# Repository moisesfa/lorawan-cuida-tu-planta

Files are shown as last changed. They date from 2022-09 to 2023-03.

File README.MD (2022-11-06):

# LoRaWAN Cuida Tu Planta

Pretendo desarrollar un nodo LoRaWAN para monitorizar las condiciones ambientales en las que crece una planta.

El cerebro será la placa de desarrollo [CubeCell](https://heltec.org/project/htcc-ab01/) del fabricante [Heltec Automation](https://heltec.org/). La placa a día de hoy (Septiembre de 20022), no se recomienda para diseños nuevos y le han puesto la etiqueta Phaseout. El fabricante recomienda una CubeCell-Dev-Board (V2) de la que todavía no hay documentación. Esto carece de importancia en este proyecto que pretende ser meramente educativo. También, pueden ser interesantes las modificaciones a la nueva versión en un futuro.
En Octubre de 2022 ya hay documentación de la versión 2 de la [CubeCell-Dev-Board](https://heltec.org/project/htcc-ab01-v2/). A falta de pruebas, parece que va a ser compatible con la placa diseñada.  

Se ha diseñado un circuito impreso para alimentar el circuito con una batería 18650 y poder conectar fácilmente los sensores i2c a usar. Vea la documentación [aquí](/hardware/README.md)

Temperatura, Humedad, Presión Atmosférica se obtendran con el sensor [BME280](https://www.luisllamas.es/sensor-ambiental-arduino-bme280/)

Para el nivel de luz, un sensor digital [BH1750](https://www.luisllamas.es/medir-cantidad-de-luxes-con-arduino-y-el-luxometro-bh1750/)

El sensor de humedad del suelo será un [higrómetro capacitivo](https://www.luisllamas.es/sensor-de-humedad-del-suelo-capacitivo-y-arduino/) para el que necesitaremos un conversor analógico digital (ADC) como el [ADS1115](https://www.luisllamas.es/entrada-analogica-adc-de-16-bits-con-arduino-y-ads1115/) ya que la CubeCell no dispone de entradas analógicas libres. Esto también nos dará la posibilidad de conectar hasta 4 sensores de humedad de suelo. 

<div style="text-align: center;">

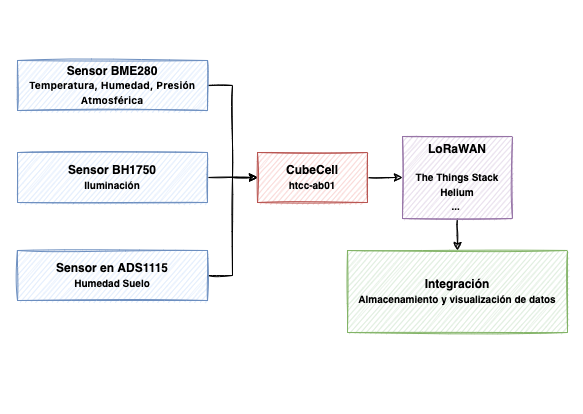
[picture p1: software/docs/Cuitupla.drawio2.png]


</div>

## Fases del proyecto 

- Lectura de los sensores con el puerto serie.
    - [BME280](/software/02_inicio_bme280/README.md)
    - [BH1750](/software/03_inicio_bh1750/README.md)
    - [Conversor analógico-digital para humedad del suelo](/software/04_inicio_ads1115/README.md)
    - [Lectura de todos los sensores](/software/05_sensores_todos/README.md)

- Envio de datos LoRaWAN
    - [Inicio con LoRaWAN](/software/06_inicio_lorawan/README.md)
    - [Lectura de los sensores a LoRaWAN](/software/07_sensores_lorawan/README.md)

## Resultado final

Para proteger el sensor de humedad del suelo he seguido estas [instrucciones](https://www.instructables.com/Waterproofing-a-Capacitance-Soil-Moisture-Sensor/)

El sensor de luminosidad se ha usado en este [formato de bola](https://a.aliexpress.com/_ExYB4vB) para una mejor colocación.

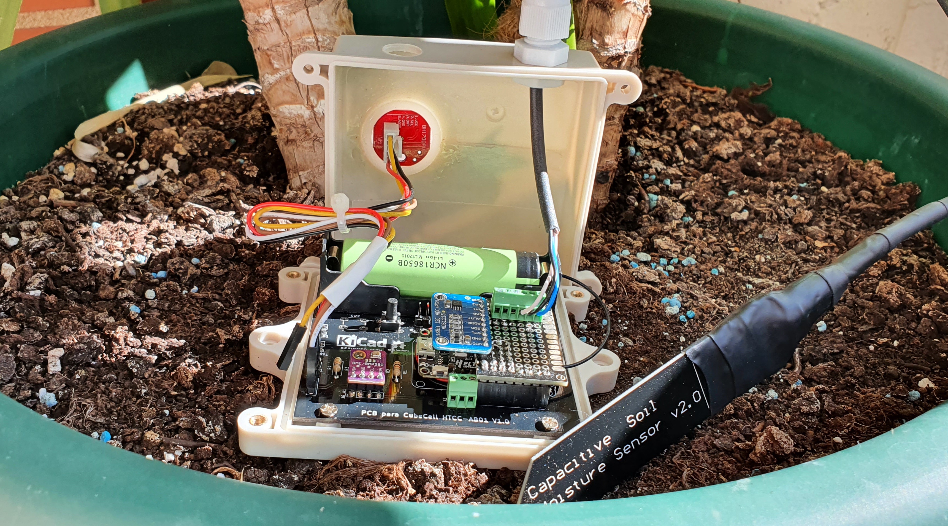
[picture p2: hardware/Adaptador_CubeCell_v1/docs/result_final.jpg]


## Análisis de consumo

He analizado el consumo con el [Power-Profiler-Kit-2](https://www.nordicsemi.com/Products/Development-hardware/Power-Profiler-Kit-2) y dejo aquí los resultados.

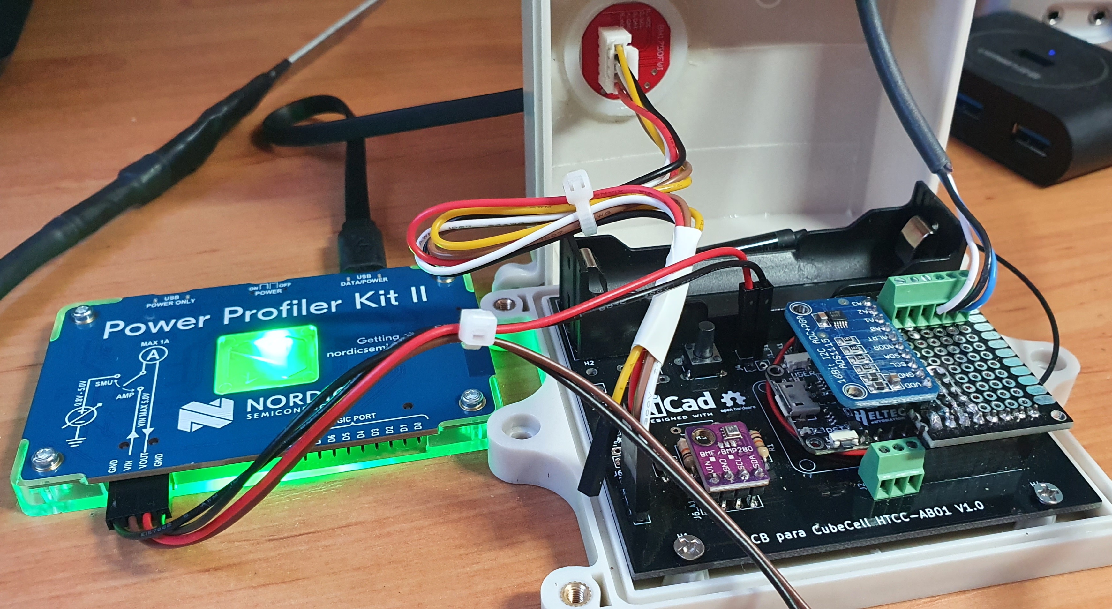
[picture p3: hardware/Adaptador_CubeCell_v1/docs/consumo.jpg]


<div style="text-align: center;">

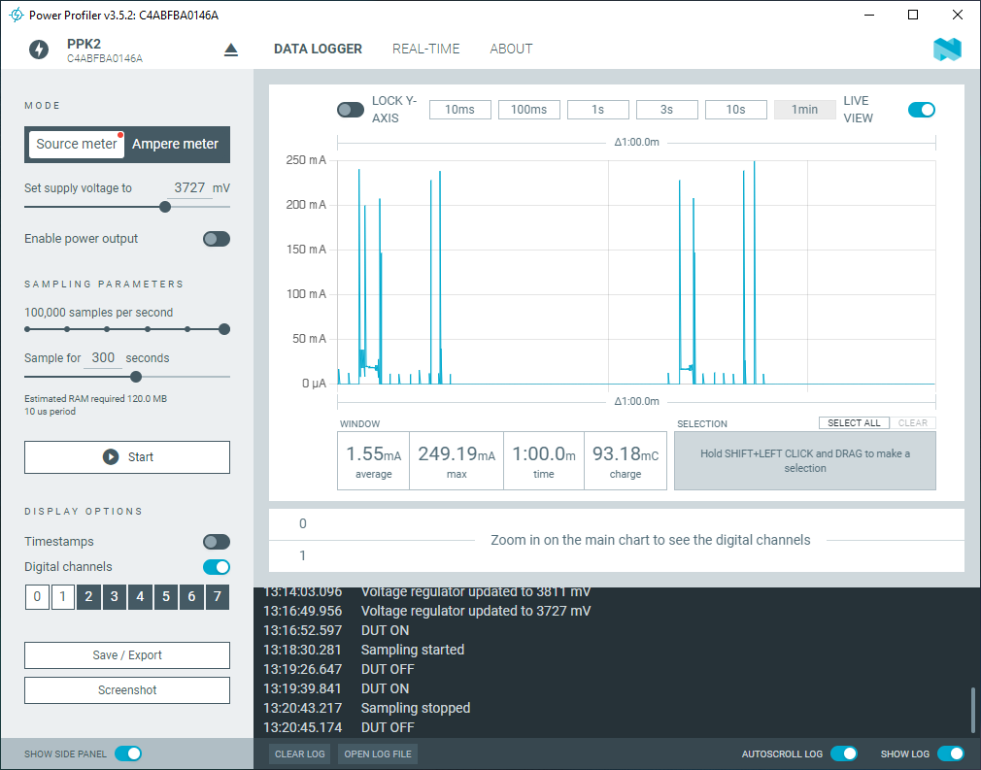
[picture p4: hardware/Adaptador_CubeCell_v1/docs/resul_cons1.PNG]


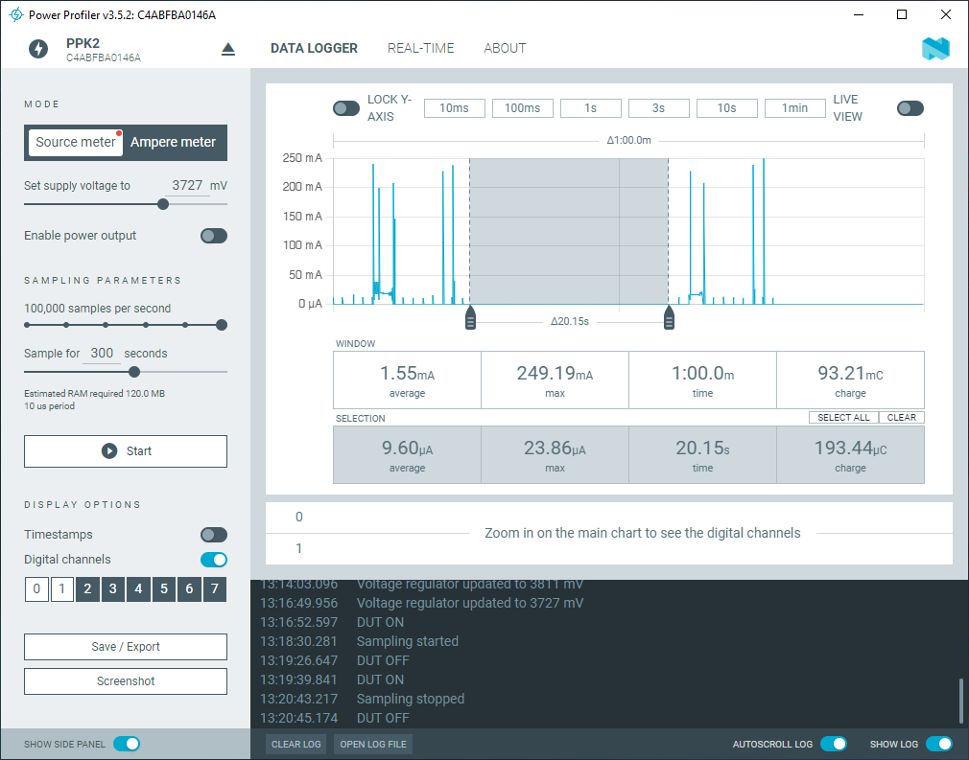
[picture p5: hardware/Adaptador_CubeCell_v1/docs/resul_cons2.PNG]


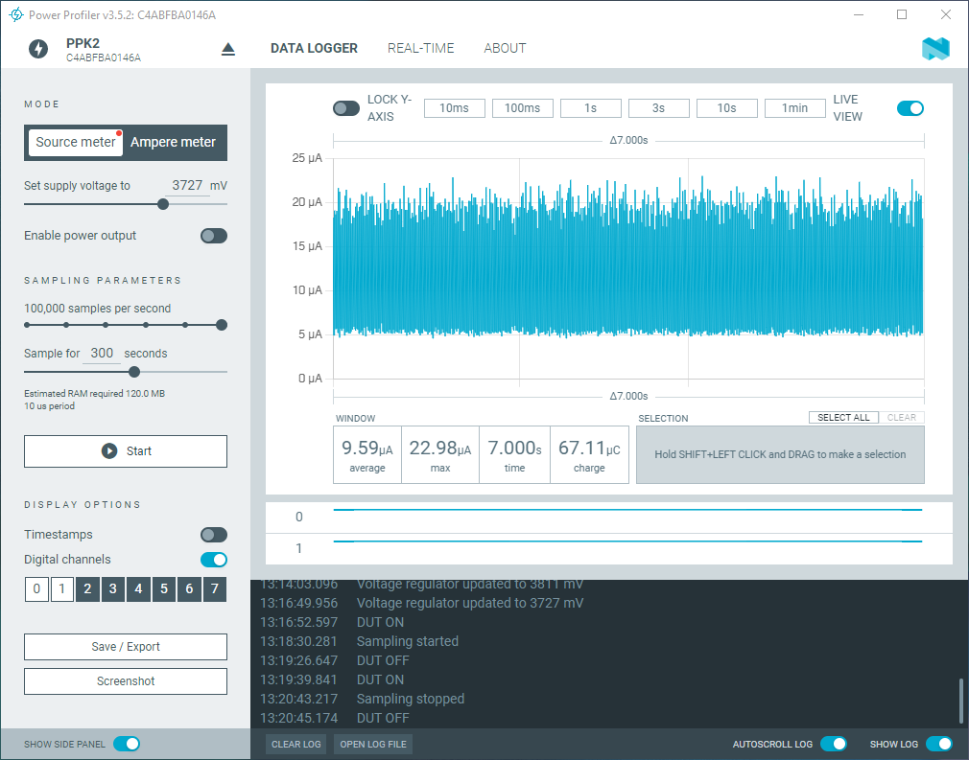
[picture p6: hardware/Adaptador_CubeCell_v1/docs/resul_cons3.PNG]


</div>

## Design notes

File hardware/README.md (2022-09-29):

# Documentación sobre circuito impreso adaptador

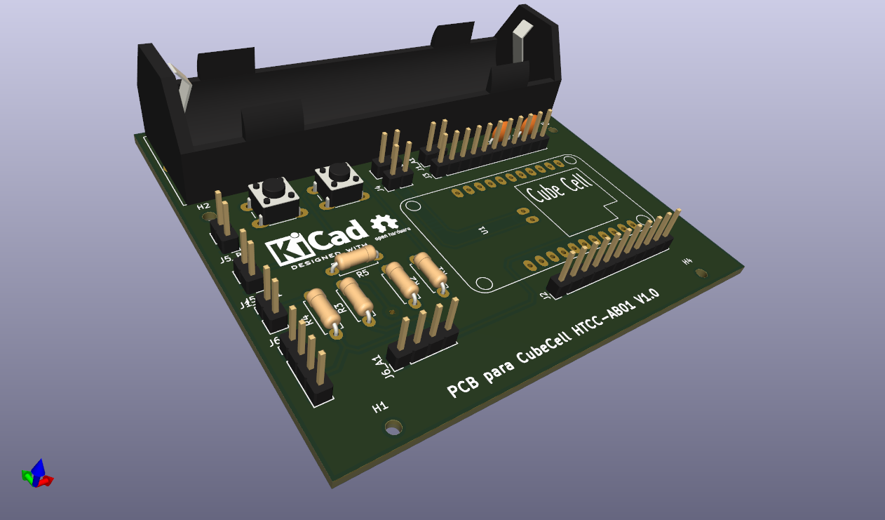
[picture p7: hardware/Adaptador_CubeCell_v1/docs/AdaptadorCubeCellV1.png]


[Esquema](./Adaptador_CubeCell_v1/docs/Adaptador_CubeCell_v1_sch.pdf) y [PCB](./Adaptador_CubeCell_v1/docs/Adaptador_CubeCell_v1_pcb.pdf) diseñados con [Kicad](https://www.kicad.org/)

Se ha diseñado para que se pueda alojar en esta [caja](https://a.aliexpress.com/_dWu4tJt)  

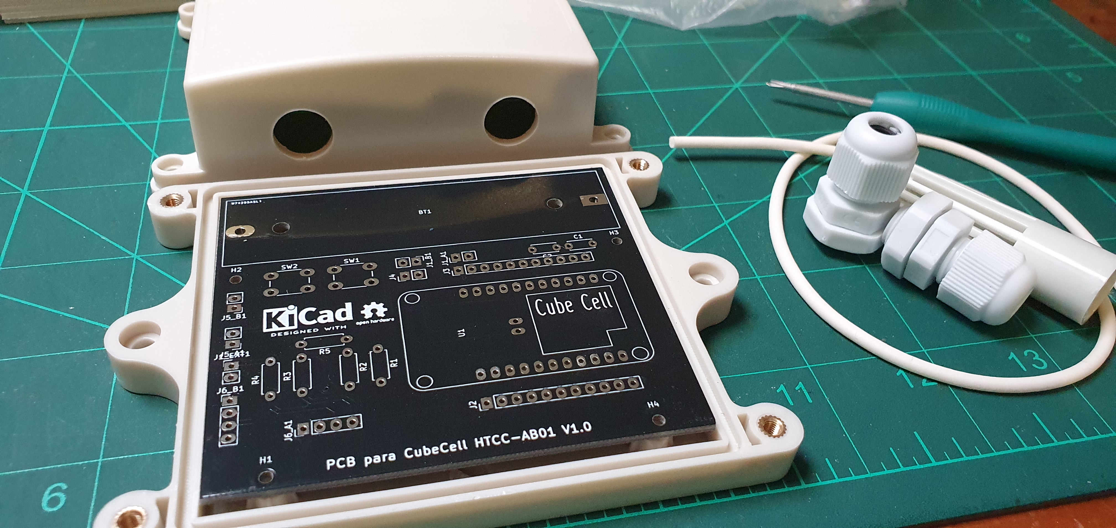
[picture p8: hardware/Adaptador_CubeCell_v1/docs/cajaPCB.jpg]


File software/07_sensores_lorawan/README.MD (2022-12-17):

# sensores_lorawan
 
Este programa lee los todos los sensores y envía la información a LoRaWAN con solo cambiar esta parte del código por las appEui[], devEui[] y appKey[] de su nodo final:

````
/* OTAA para*/
uint8_t appEui[] = { 0x00, 0x00, 0x00, 0x00, 0x00, 0x00, 0x00, 0x00 }; // your appEui
uint8_t devEui[] = { 0x00, 0x00, 0x00, 0x00, 0x00, 0x00, 0x00, 0x00 }; // your devEui
uint8_t appKey[] = { 0x00, 0x00, 0x00, 0x00, 0x00, 0x00, 0x00, 0x00, 0x00, 0x00, 0x00, 0x00, 0x00, 0x00, 0x00, 0x00 }; // your appKey
````

Practicamente todo se basa en la [documentación de Heltec Automation](https://github.com/HelTecAutomation/CubeCell-Arduino/tree/master/libraries/LoRa/examples/LoRaWAN).

El ciclo de trabajo de la aplicación es el siguiente:

1. Se une con la aplicación LoRaWAN.
2. Lee y envía los datos a LoRaWAN.
3. Se duerme durante un tiempo appTxDutyCycle = 30 * 1000; (30 segundos para pruebas).
4. Se despierta, lee los sensores y vuelve a enviar los datos.
5. Los pasos 3 y 4 se repiten hasta que la batería se agota o se resetea el dispositivo.

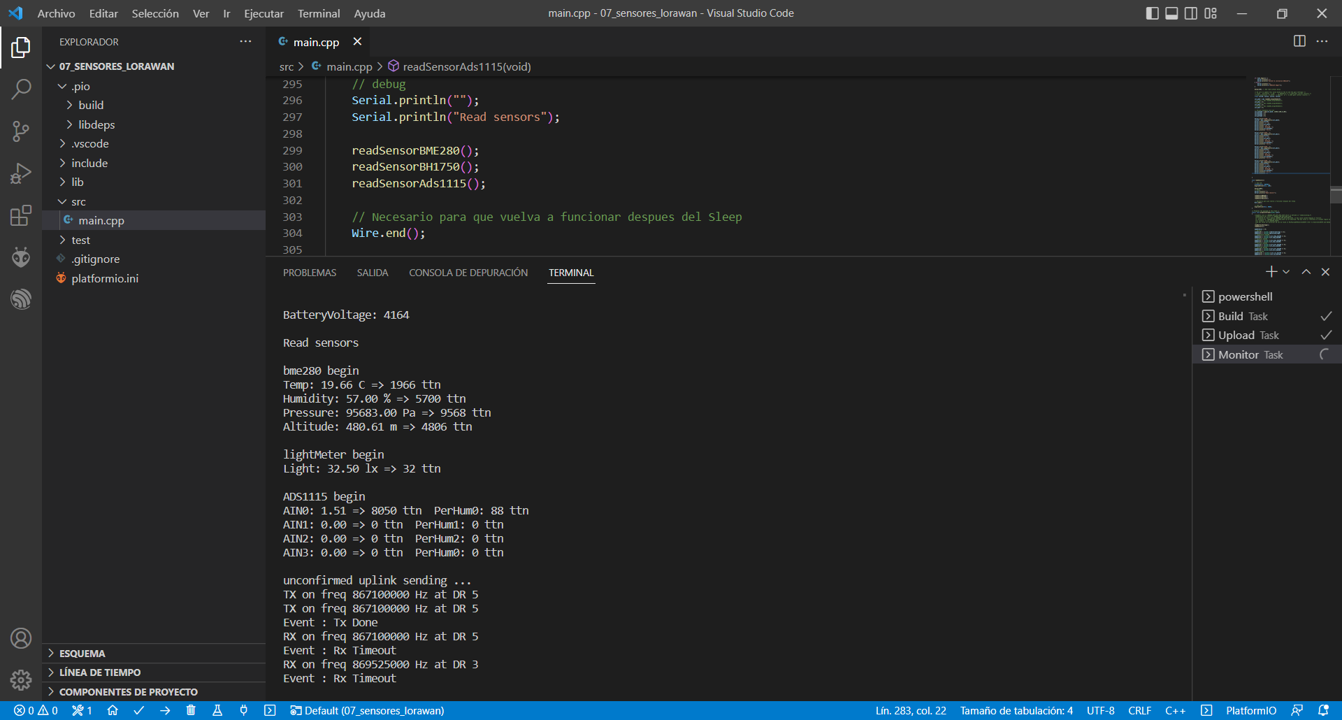
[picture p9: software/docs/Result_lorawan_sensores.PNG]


Ejemplo en The Things Stack: 

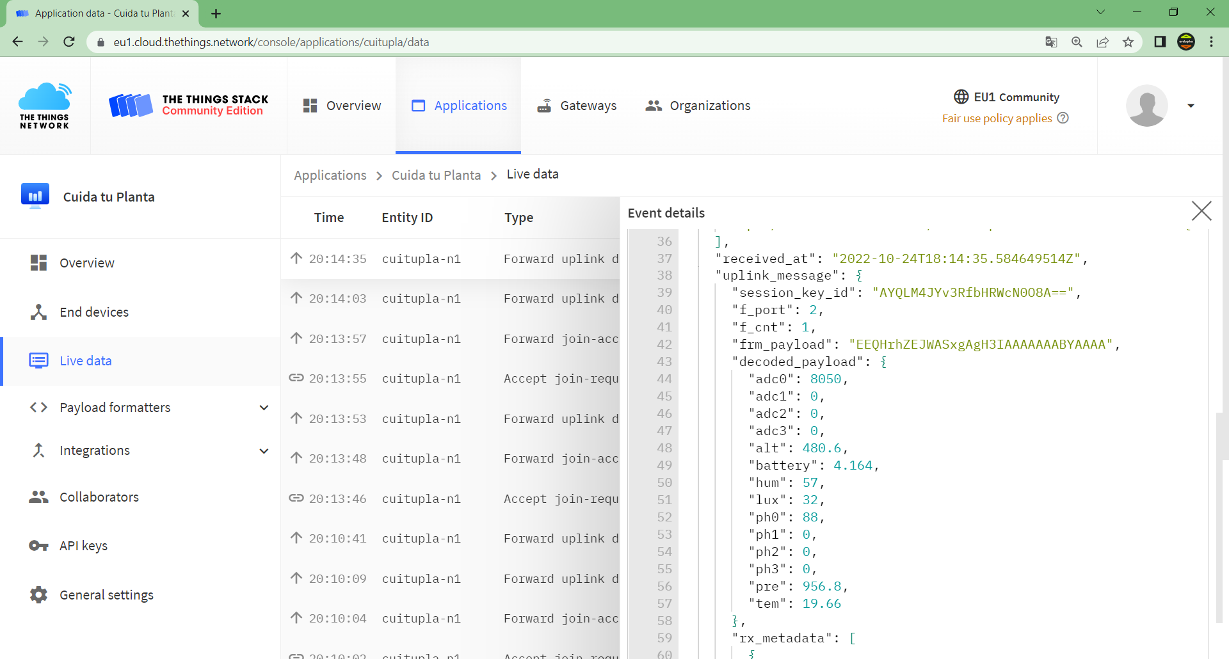
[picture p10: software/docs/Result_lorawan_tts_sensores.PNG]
Ejemplo en The Things Stack


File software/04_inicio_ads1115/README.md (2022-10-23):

# inicio_ads1115
 
Este programa lee los valores de un sensor analógico que será un sensor de humedad del suelo, usando el programa alojado en la [documentación de cubecell](https://github.com/HelTecAutomation/CubeCell-Arduino/blob/master/libraries/Sensor_ThirdParty/examples/ADS1X15/singleended/singleended.ino) y adaptado para [PlatformIO](https://platformio.org/). Funciona con la librería de [Adafruit_ADS1x15](https://github.com/adafruit/Adafruit_ADS1X15). Yo solamente le he añadido un poco de color con el RGB de la placa. 

La conexión eléctrica es muy simple: 

| CubeCell | Ads1115 |
| -- | -- |
| VEXT | VDD |
| GND | GND |
| SCL | SCL |
| SDA | SDA |
  
En A0, A1, A2, A3 se conectan las señales analógicas de los sensores de humedad de suelo.

## Calibración

Buscamos el valor del conversor con el sensor de humedad seco:

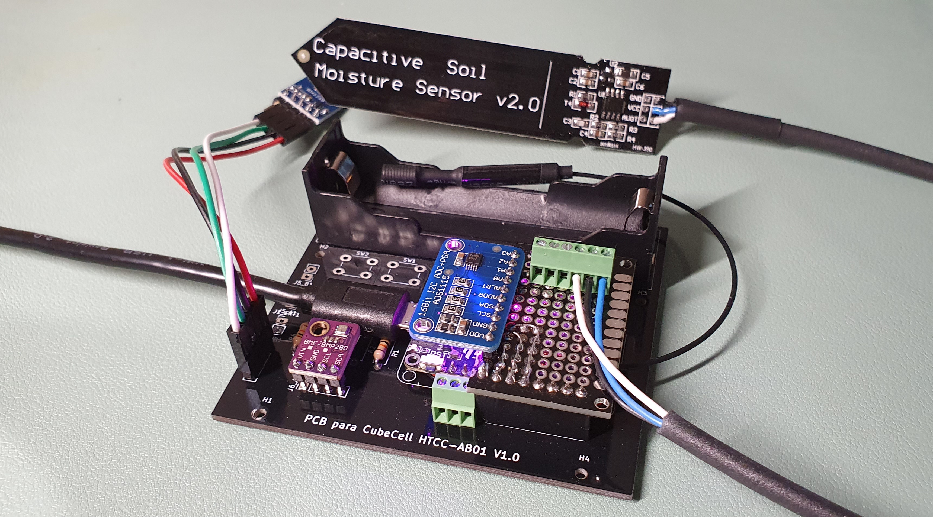
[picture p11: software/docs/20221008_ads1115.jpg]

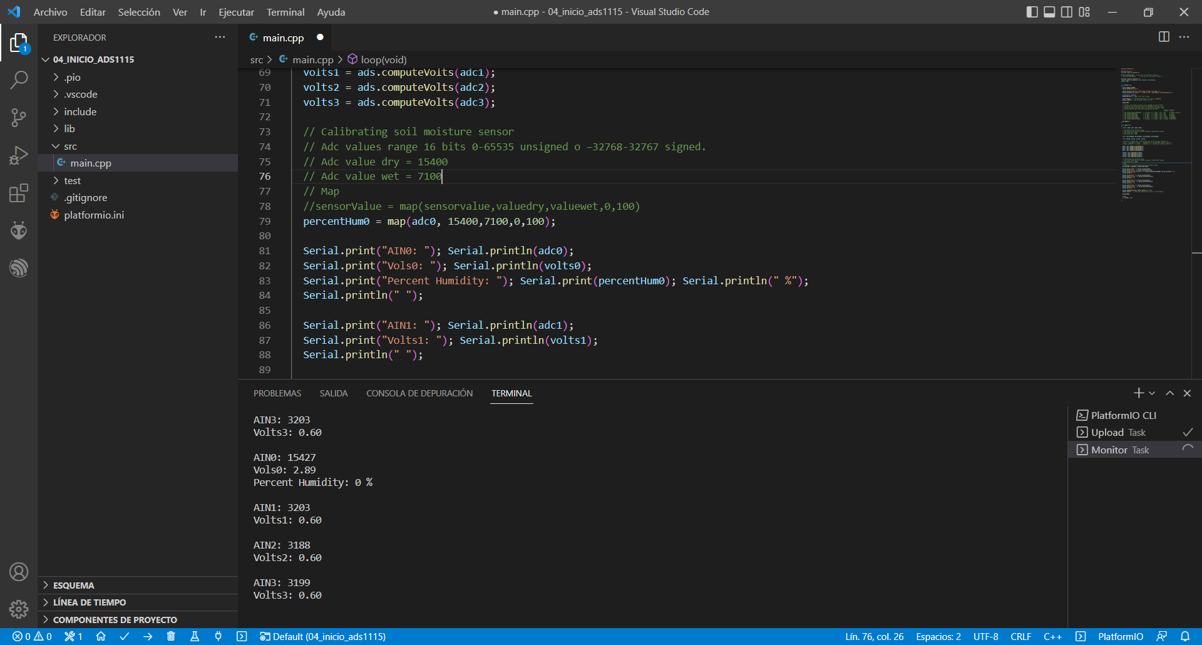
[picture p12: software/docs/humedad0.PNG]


Buscamos el valor del conversor con el sensor de humedad humedo:

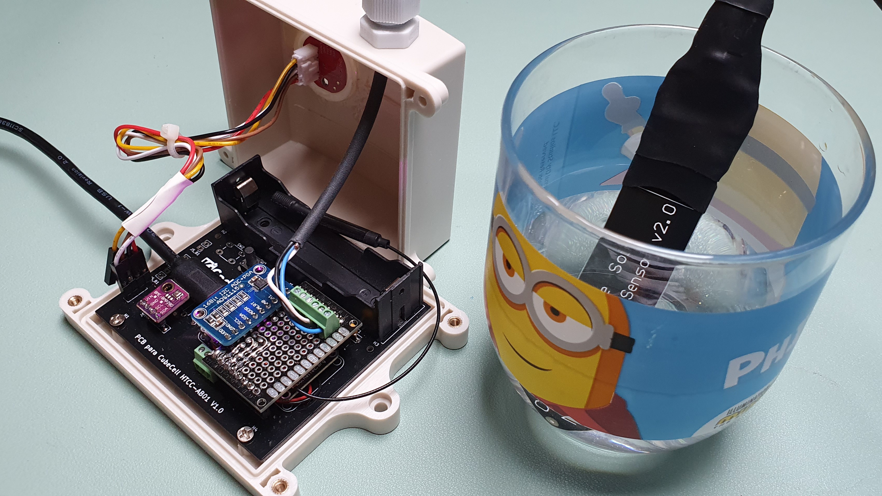
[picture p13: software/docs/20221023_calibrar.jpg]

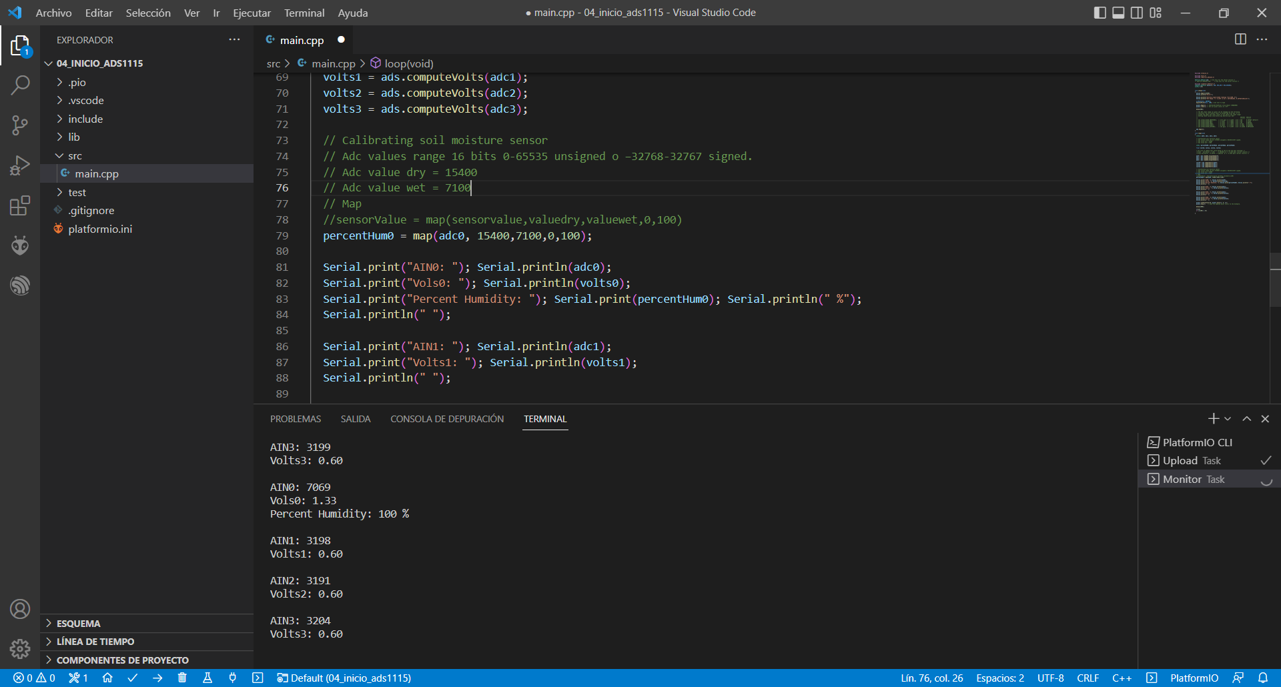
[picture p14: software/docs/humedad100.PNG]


Y mapeamos los valores con la función map de Arduino.

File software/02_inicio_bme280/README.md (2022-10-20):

# inicio_bme280

Este programa lee los valores de un sensor BME280 usando la librería [Grove_BME280 de Seeedstudo](https://github.com/Seeed-Studio/Grove_BME280) alojado en la [documentación de cubecell](https://github.com/HelTecAutomation/CubeCell-Arduino/blob/master/libraries/Sensor_ThirdParty/examples/BME280/bme280_example/bme280_example.ino) y adaptado para [PlatformIO](https://platformio.org/). Yo solamente le he añadido un poco de color con el RGB de la placa.

La conexión eléctrica es muy simple: 

| CubeCell | Bme280 |
| -- | -- |
| VEXT | VIN |
| GND | GND |
| SCL | SCL |
| SDA | SDA |

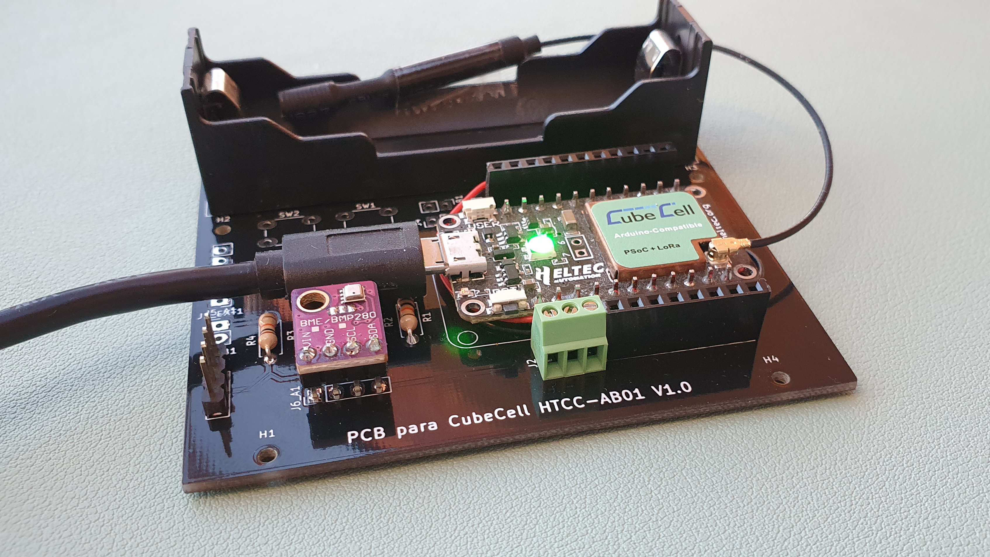
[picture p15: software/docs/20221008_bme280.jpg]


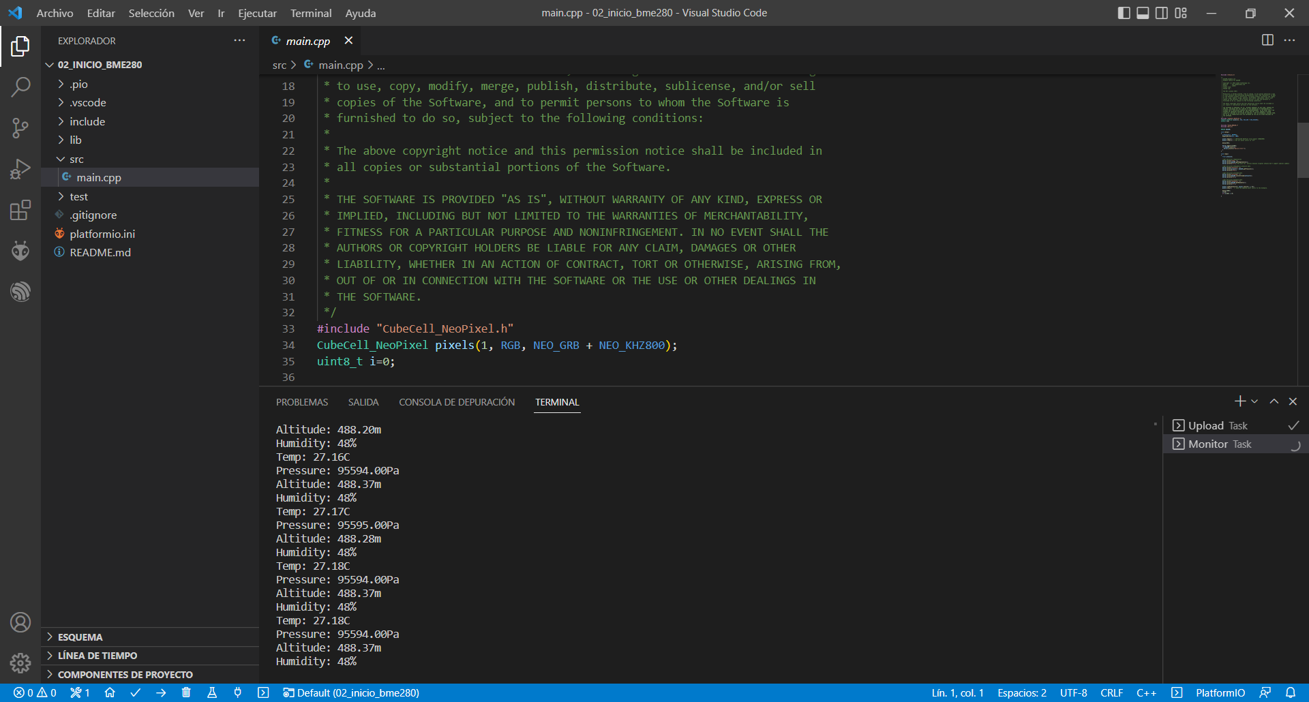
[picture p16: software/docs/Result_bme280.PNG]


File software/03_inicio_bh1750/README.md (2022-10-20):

# inicio_bh1750
 
Este programa lee los valores de un sensor BH1750 usando el programa alojado en la [documentación de cubecell](https://github.com/HelTecAutomation/CubeCell-Arduino/blob/master/libraries/SensorBasic/examples/BH1750/BH1750test/BH1750test.ino) y adaptado para [PlatformIO](https://platformio.org/). No es neceario añadir ninguna libreria. Yo solamente le he añadido un poco de color con el RGB de la placa.

La conexión eléctrica es muy simple: 

| CubeCell | Bh1750 |
| -- | -- |
| VEXT | VDD |
| GND | GND |
| SCL | SCL |
| SDA | SDA |

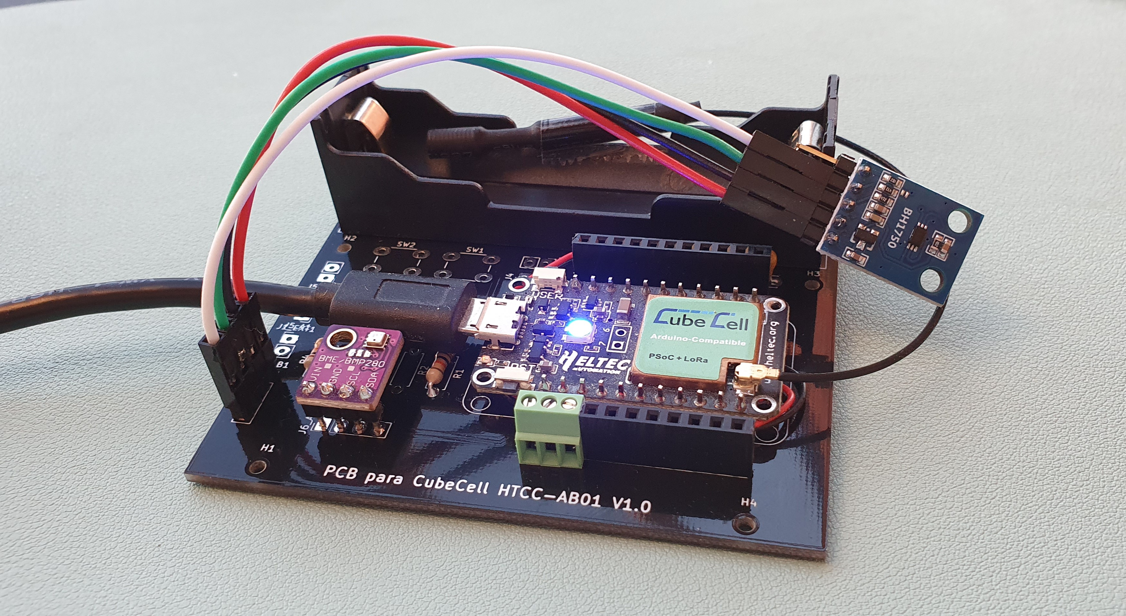
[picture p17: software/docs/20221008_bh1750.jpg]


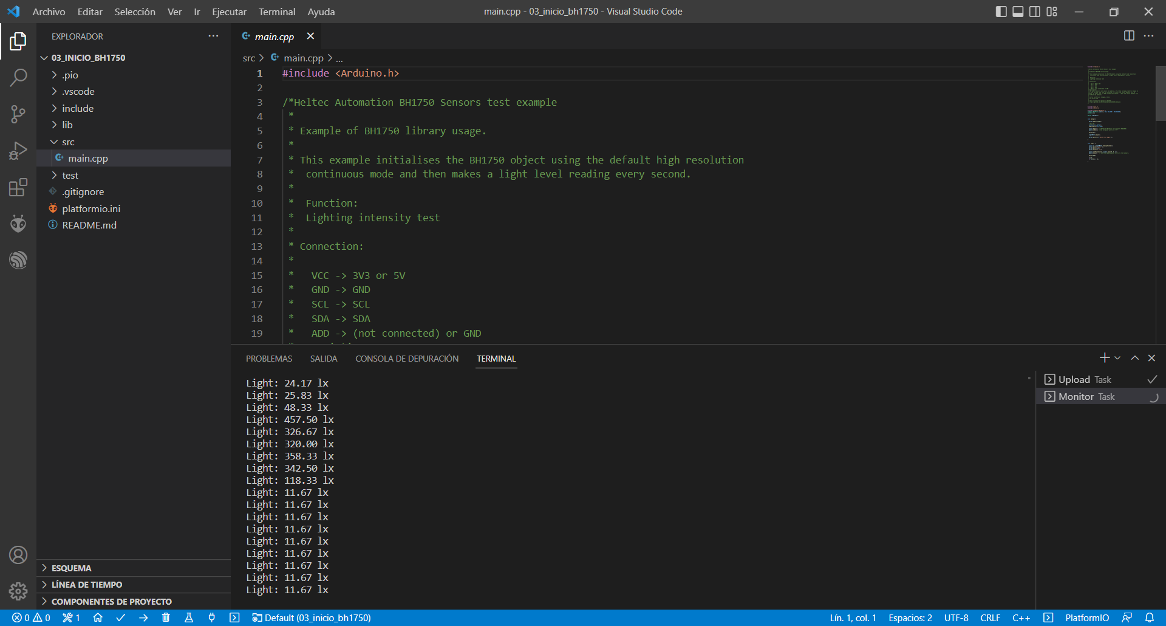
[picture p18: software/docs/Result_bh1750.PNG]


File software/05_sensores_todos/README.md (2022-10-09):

# sensores_todos
 
Este programa lee los valores de todos los sensores, BME280, BH1750 y sensores analógicos en ADS1115. La información de todos ellos se envia por el puerto serie y se cambia el color del led RGB en cada lectura.   

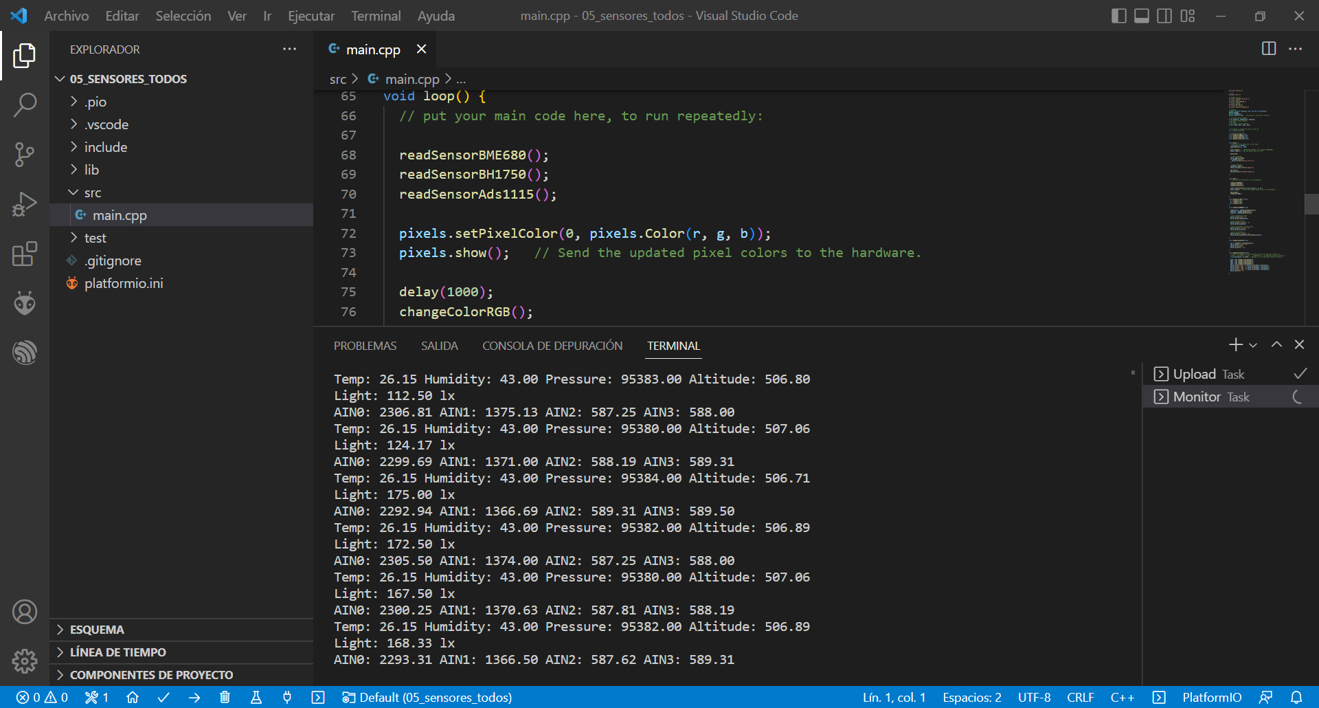
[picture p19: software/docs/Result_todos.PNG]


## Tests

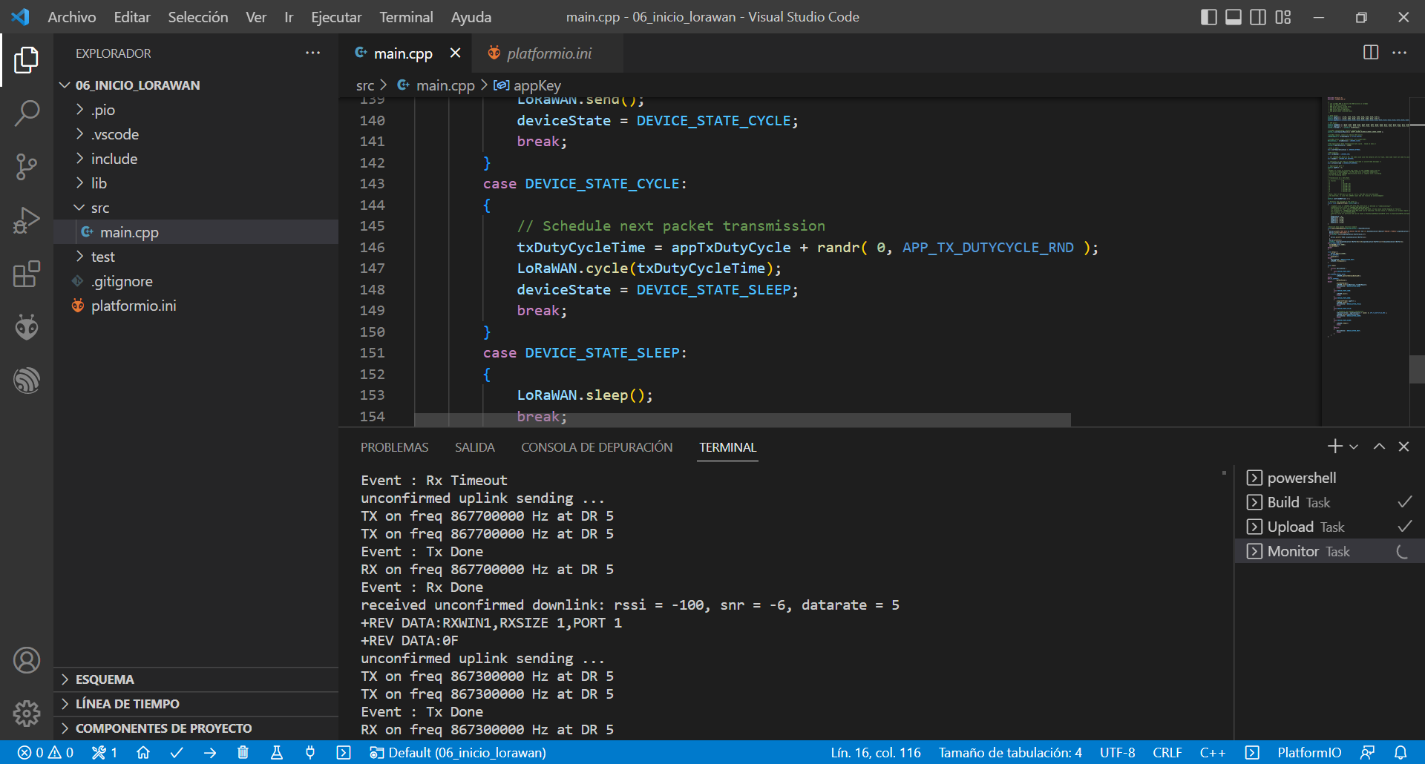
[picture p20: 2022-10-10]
software/docs/Result_lorawan.PNG

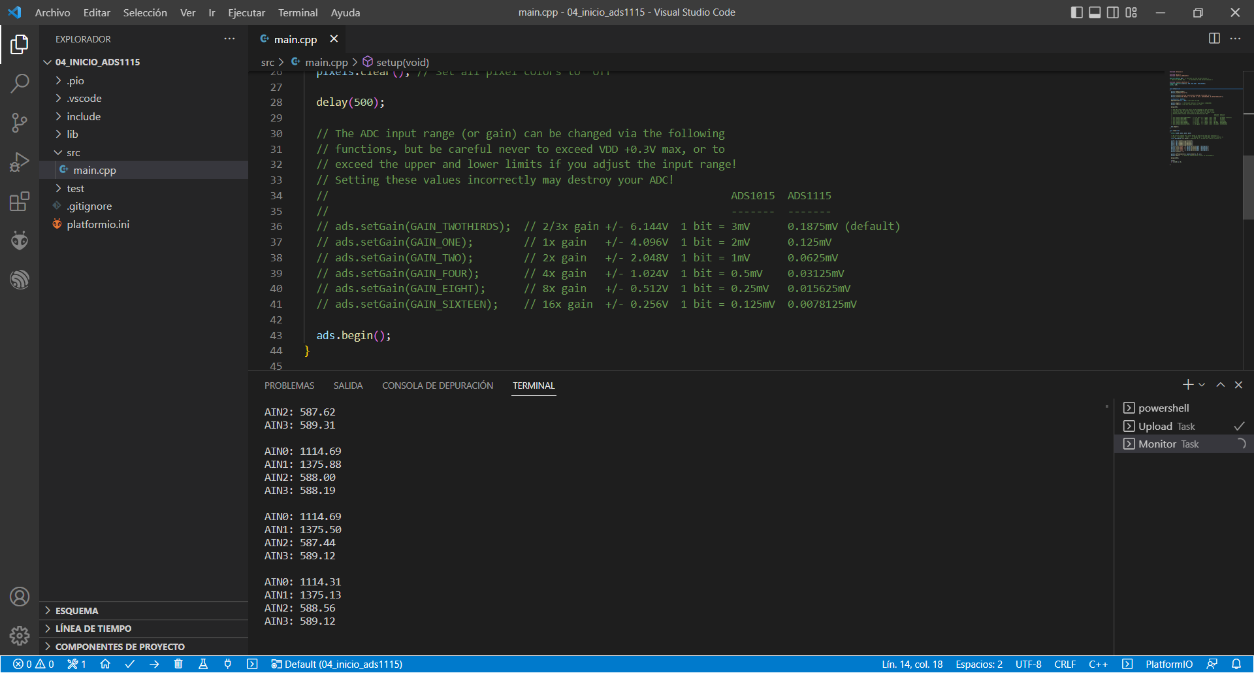
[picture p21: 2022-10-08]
software/docs/Result_ads1115.PNG

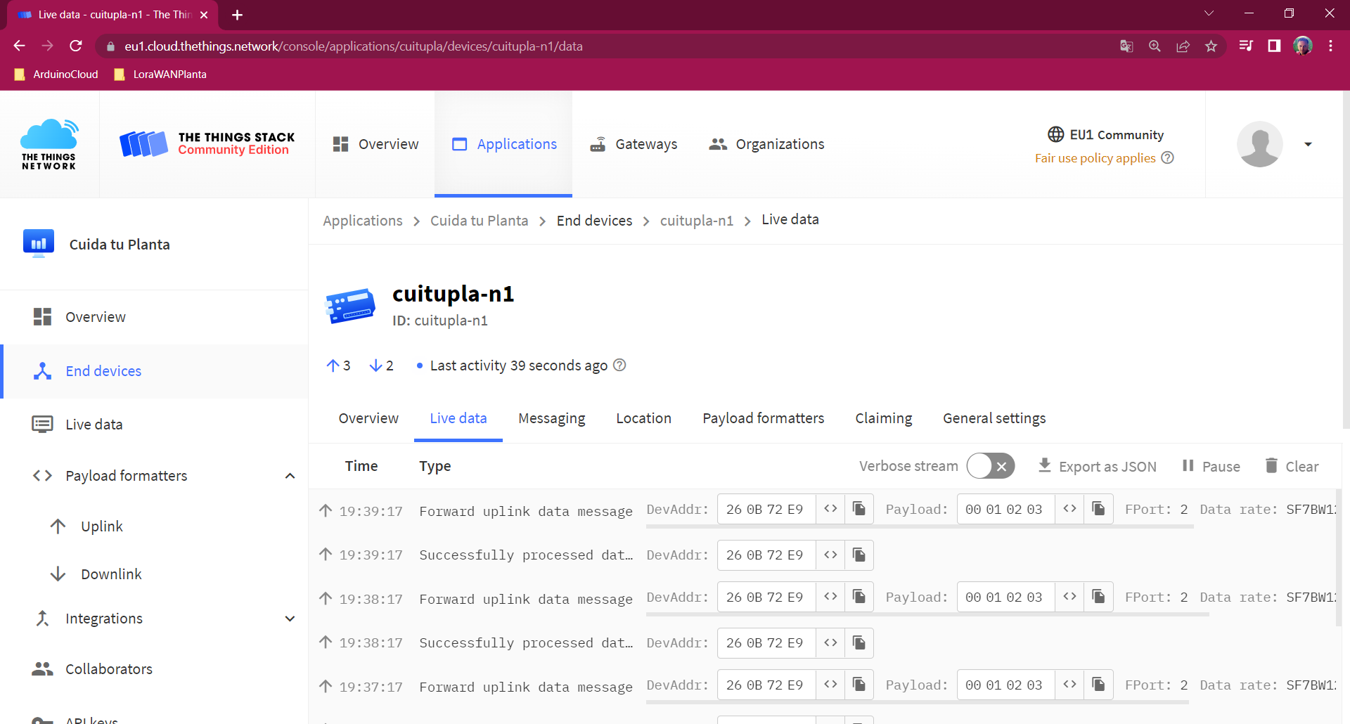
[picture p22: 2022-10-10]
software/docs/Result_lorawan_tts.PNG

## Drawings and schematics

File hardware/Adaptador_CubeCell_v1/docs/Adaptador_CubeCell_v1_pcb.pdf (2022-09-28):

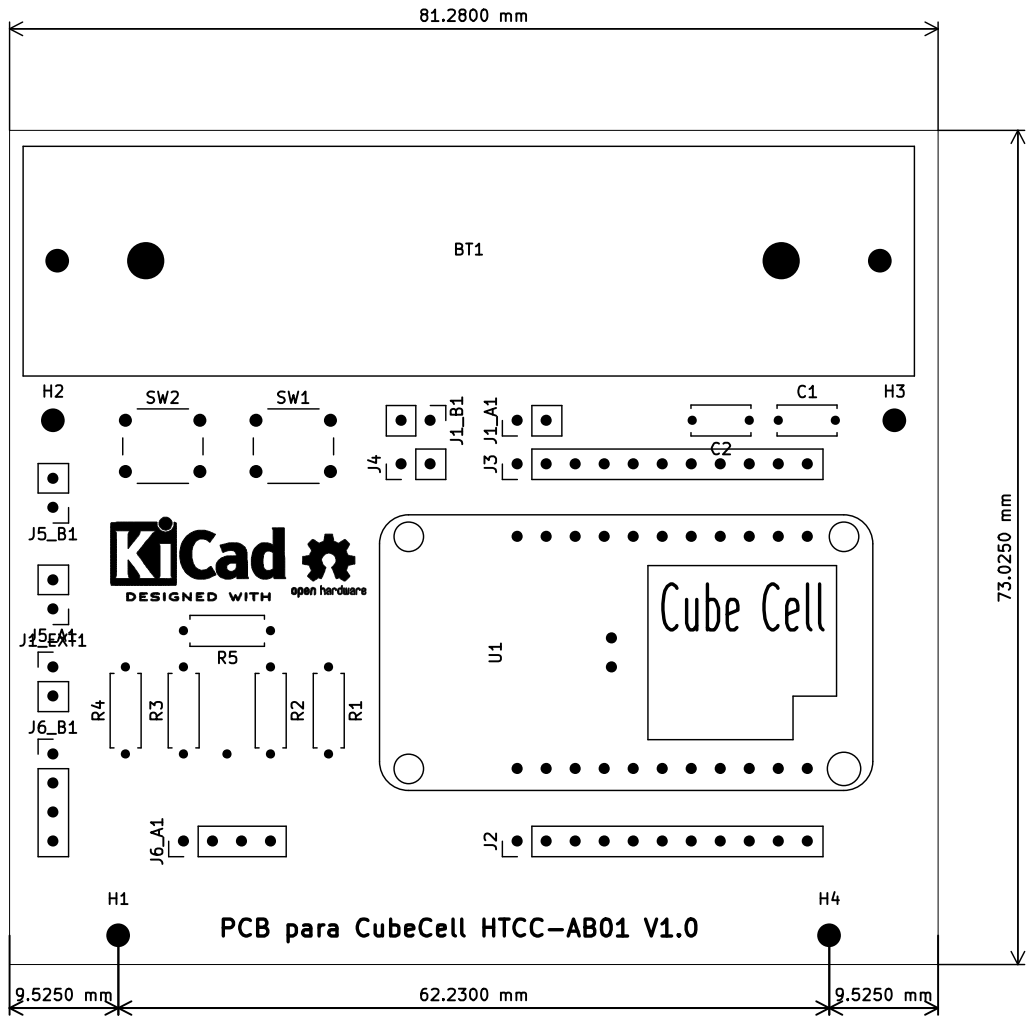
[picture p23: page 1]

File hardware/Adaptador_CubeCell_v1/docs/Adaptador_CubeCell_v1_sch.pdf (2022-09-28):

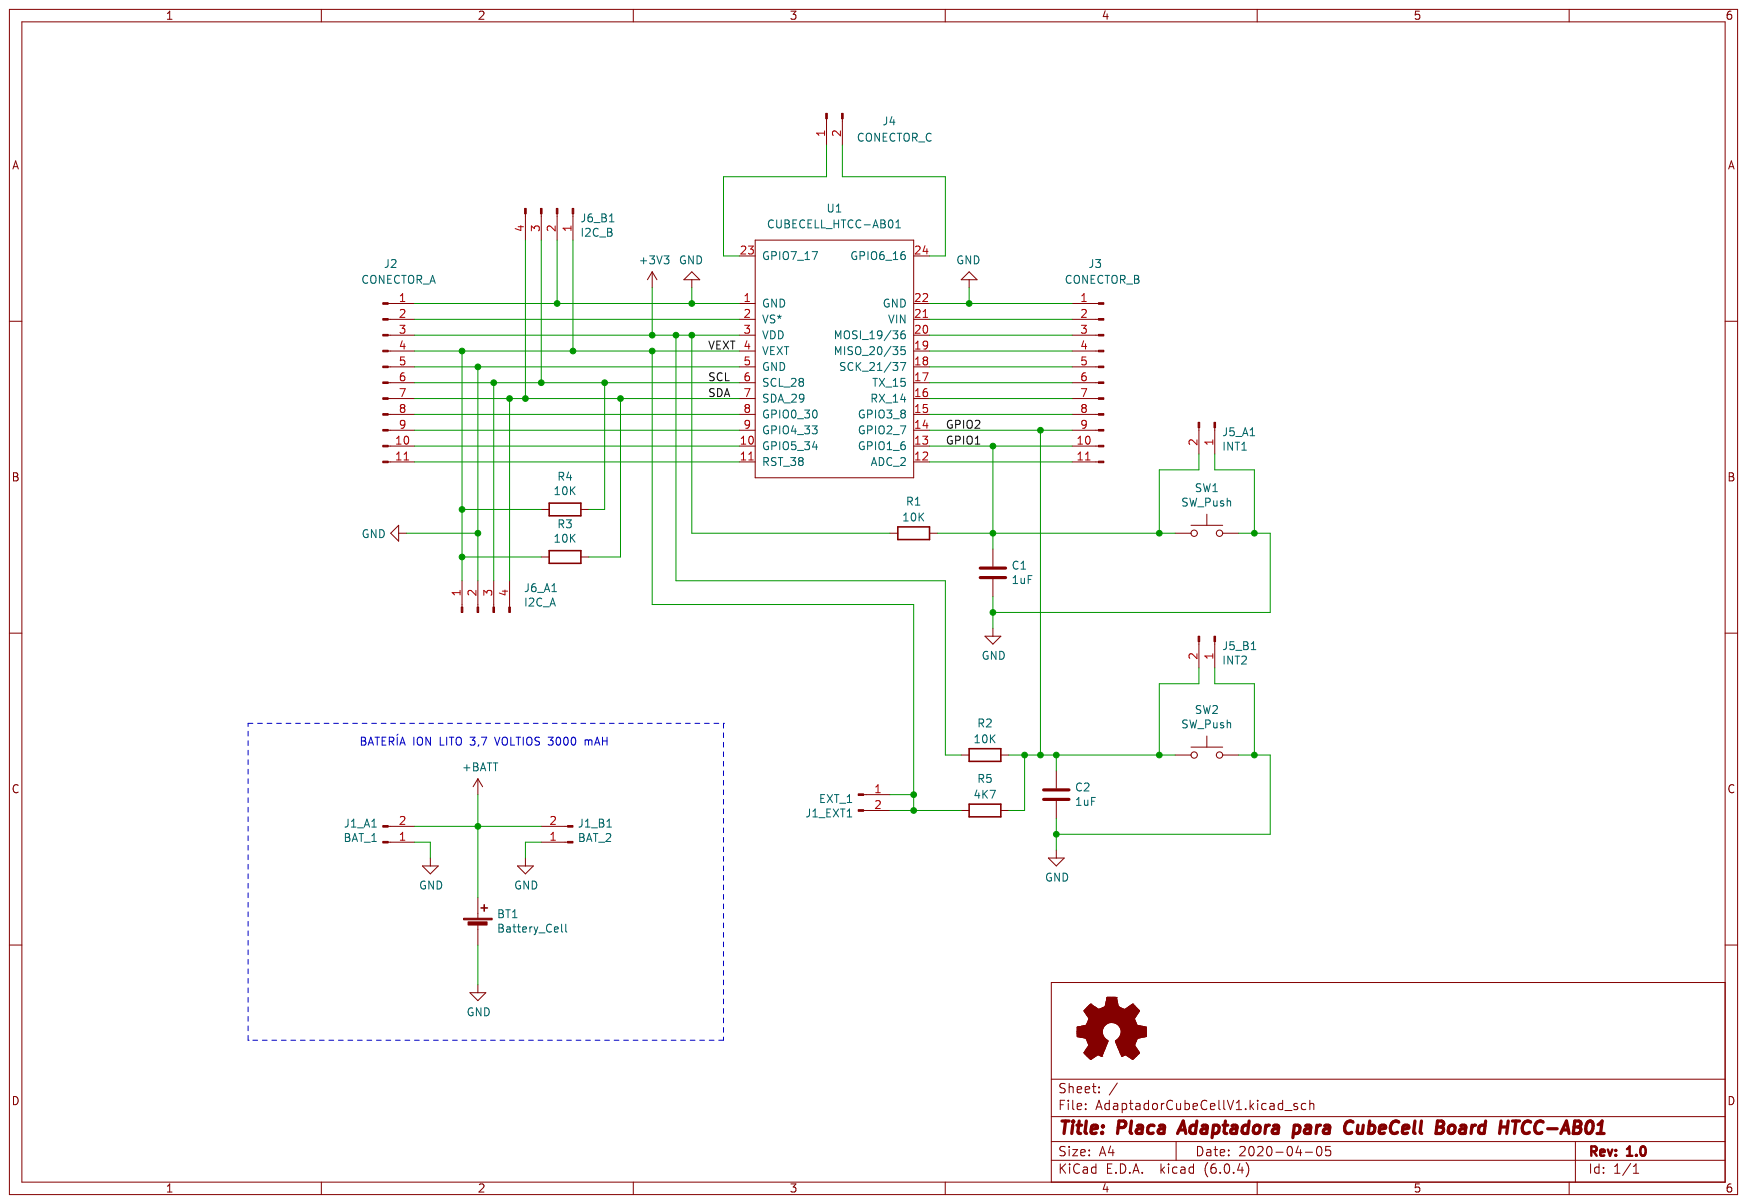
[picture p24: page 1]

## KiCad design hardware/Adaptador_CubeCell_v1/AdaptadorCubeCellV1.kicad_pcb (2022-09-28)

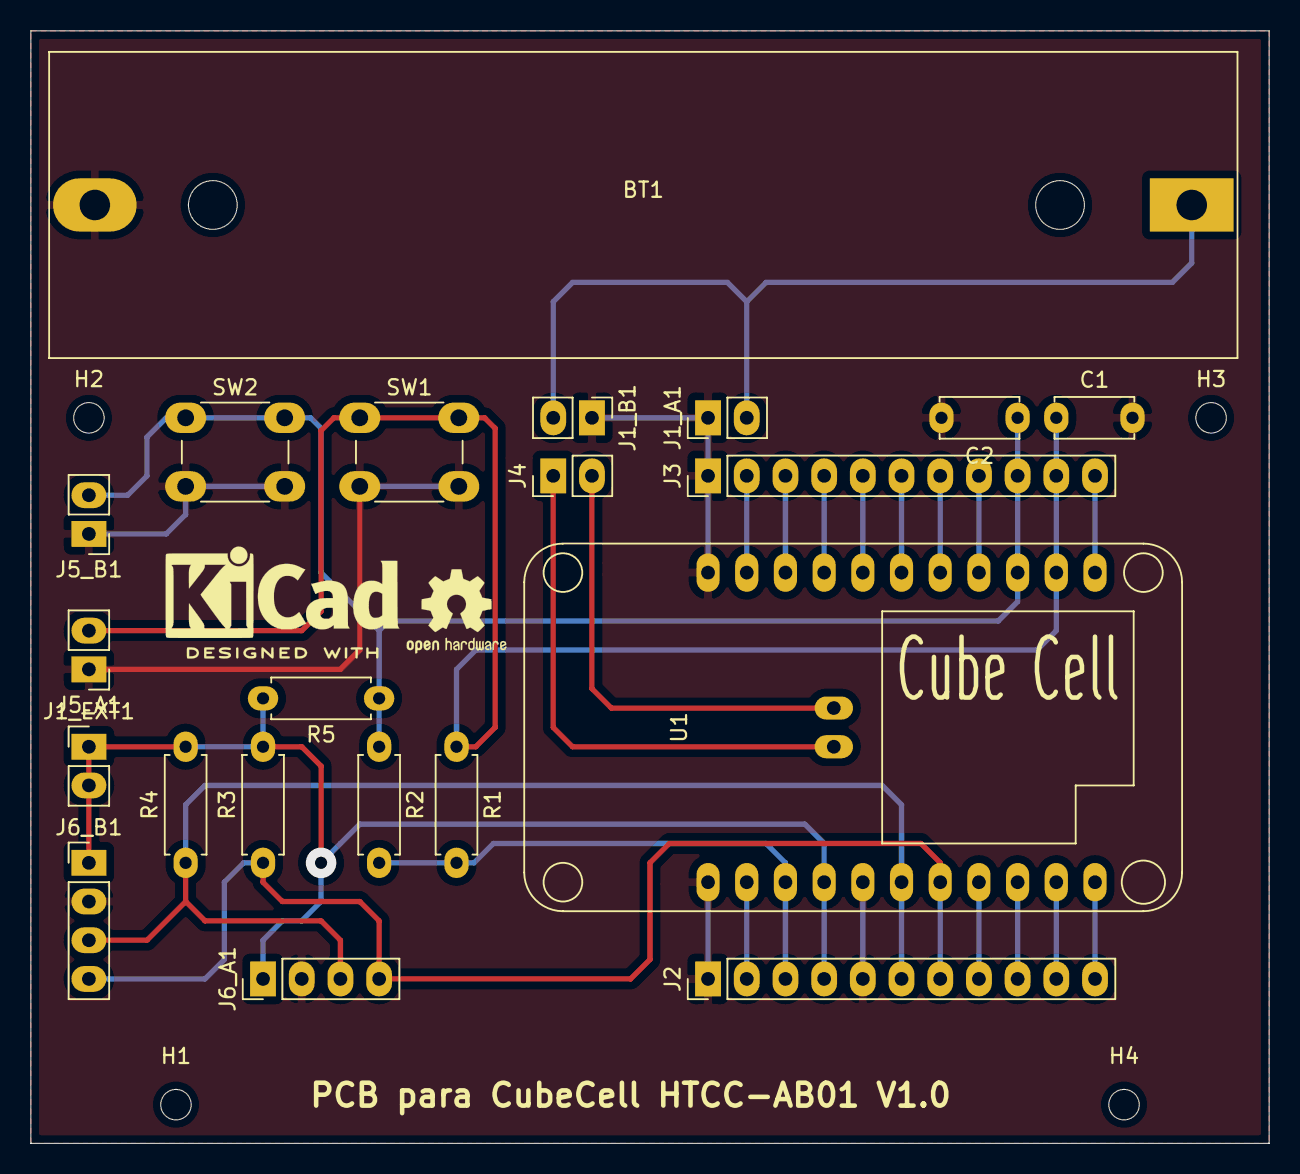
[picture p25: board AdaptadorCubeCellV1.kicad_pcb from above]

Board: 2 copper layers, 81.3 x 73.0 mm, 25 parts (0 on the bottom side), 23 nets.

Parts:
BT1: Battery_Cell; BatteryHolder_MPD_BH-18650-PC2
C1, C2: 1uF; C_Disc_D5.0mm_W2.5mm_P5.00mm
H1, H2, H3, H4: MountingHole_2mm
J1_A1: BAT_1; PinHeader_1x02_P2.54mm_Vertical_custom
J1_B1: BAT_2; PinHeader_1x02_P2.54mm_Vertical_custom
J1_EXT1: EXT_1; PinHeader_1x02_P2.54mm_Vertical_custom
J2: CONECTOR_A; PinHeader_1x11_P2.54mm_Vertical
J3: CONECTOR_B; PinHeader_1x11_P2.54mm_Vertical
J4: CONECTOR_C; PinHeader_1x02_P2.54mm_Vertical_custom
J5_A1: INT1; PinHeader_1x02_P2.54mm_Vertical_custom
J5_B1: INT2; PinHeader_1x02_P2.54mm_Vertical_custom
J6_A1: I2C_A; PinHeader_1x04_P2.54mm_Vertical
J6_B1: I2C_B; PinHeader_1x04_P2.54mm_Vertical
R1, R2, R3, R4: 10K; R_Axial_DIN0207_L6.3mm_D2.5mm_P7.62mm_Horizontal
R5: 4K7; R_Axial_DIN0207_L6.3mm_D2.5mm_P7.62mm_Horizontal
SW1, SW2: SW_Push; SW_PUSH_6mm_H5mm
U1: CUBECELL_HTCC-AB01; CubeCell_HTCC-AB01

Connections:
+3V3: J2.3, R1.2, R2.2, U1.3
+BATT: BT1.1, J1_A1.2, J1_B1.2
/GPIO1: C1.1, J3.10, J5_A1.2, R1.1, SW1.1, U1.13
/GPIO2: C2.1, J3.9, J5_B1.2, R2.1, R5.1, SW2.1, U1.14
/SCL: J2.6, J6_A1.3, J6_B1.3, R4.1, U1.6
/SDA: J2.7, J6_A1.4, J6_B1.4, R3.1, U1.7
/VEXT: J1_EXT1.1, J1_EXT1.2, J2.4, J6_A1.1, J6_B1.1, R3.2, R4.2, R5.2, U1.4
GND: BT1.2, C1.2, C2.2, J1_A1.1, J1_B1.1, J2.1, J2.5, J3.1, J5_A1.1, J5_B1.1, J6_A1.2, J6_B1.2, SW1.2, SW2.2, U1.1, U1.5, U1.22
unnamed: J2.2, U1.2
unnamed: J2.8, U1.8
unnamed: J2.9, U1.9
unnamed: J2.10, U1.10
unnamed: J2.11, U1.11
unnamed: J3.2, U1.21
unnamed: J3.3, U1.20
unnamed: J3.4, U1.19
unnamed: J3.5, U1.18
unnamed: J3.6, U1.17
unnamed: J3.7, U1.16
unnamed: J3.8, U1.15
unnamed: J3.11, U1.12
unnamed: J4.1, U1.23
unnamed: J4.2, U1.24

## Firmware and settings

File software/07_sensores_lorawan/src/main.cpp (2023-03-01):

#include <Arduino.h>
#include "LoRaWan_APP.h"

// I2C
#include <Wire.h>

// Handle led rgb
#include "CubeCell_NeoPixel.h"
// Sensor BME280
#include "Seeed_BME280.h"
// Sensor BH1750
#include <BH1750.h>
// Converter ADS1115
#include <Adafruit_ADS1X15.h>

// Serial debug
//#define DEBUG
#include "debug_utils.h"

// Objects
BME280 bme280;
BH1750 lightMeter;
Adafruit_ADS1115 ads; /* Use this for the 16-bit version */

// Variables
bool bme280_found = false;
bool bh1750_found = false;
bool ads1115_found = false;

uint16_t BatteryVoltage;
int16_t int_temp_bme280;
uint16_t int_humi_bme280;
uint16_t int_pres_bme280;
uint16_t int_alti_bme280;

// Variables sensor BH1750
uint16_t int_lux_bh1750;
// Variables sensors ads1115
int16_t int_adc0, int_adc1, int_adc2, int_adc3;
int8_t int_perHum0, int_perHum1, int_perHum2, int_perHum3;

/*
 * set LoraWan_RGB to Active,the RGB active in loraWan
 * RGB red means sending;
 * RGB purple means joined done;
 * RGB blue means RxWindow1;
 * RGB yellow means RxWindow2;
 * RGB green means received done;
 */

/* OTAA para*/
uint8_t appEui[] = {0x00, 0x00, 0x00, 0x00, 0x00, 0x00, 0x00, 0x00};												 // your appEui
uint8_t devEui[] = {0x00, 0x00, 0x00, 0x00, 0x00, 0x00, 0x00, 0x00};												 // your devEui
uint8_t appKey[] = {0x00, 0x00, 0x00, 0x00, 0x00, 0x00, 0x00, 0x00, 0x00, 0x00, 0x00, 0x00, 0x00, 0x00, 0x00, 0x00}; // your appKey

/* ABP para*/
uint8_t nwkSKey[] = {0x00, 0x00, 0x00, 0x00, 0x00, 0x00, 0x00, 0x00, 0x00, 0x00, 0x00, 0x00, 0x00, 0x00, 0x00, 0x00};
uint8_t appSKey[] = {0x00, 0x00, 0x00, 0x00, 0x00, 0x00, 0x00, 0x00, 0x00, 0x00, 0x00, 0x00, 0x00, 0x00, 0x00, 0x00};
uint32_t devAddr = (uint32_t)0x007e6ae1;

/*LoraWan channelsmask, default channels 0-7*/
uint16_t userChannelsMask[6] = {0x00FF, 0x0000, 0x0000, 0x0000, 0x0000, 0x0000};

/*LoraWan region, select in arduino IDE tools*/
LoRaMacRegion_t loraWanRegion = ACTIVE_REGION;

/*LoraWan Class, Class A and Class C are supported*/
DeviceClass_t loraWanClass = LORAWAN_CLASS;

/*the application data transmission duty cycle.  value in [ms].*/
uint32_t appTxDutyCycle = 60 * 60 * 1000;
//uint32_t appTxDutyCycle = 1 * 60 * 1000;		//Debug

/*OTAA or ABP*/
bool overTheAirActivation = LORAWAN_NETMODE;

/*ADR enable*/
bool loraWanAdr = LORAWAN_ADR;

/* set LORAWAN_Net_Reserve ON, the node could save the network info to flash, when node reset not need to join again */
bool keepNet = LORAWAN_NET_RESERVE;

/* Indicates if the node is sending confirmed or unconfirmed messages */
bool isTxConfirmed = LORAWAN_UPLINKMODE;

/* Application port */
uint8_t appPort = 2;
/*!
 * Number of trials to transmit the frame, if the LoRaMAC layer did not
 * receive an acknowledgment. The MAC performs a datarate adaptation,
 * according to the LoRaWAN Specification V1.0.2, chapter 18.4, according
 * to the following table:
 *
 * Transmission nb | Data Rate
 * ----------------|-----------
 * 1 (first)       | DR
 * 2               | DR
 * 3               | max(DR-1,0)
 * 4               | max(DR-1,0)
 * 5               | max(DR-2,0)
 * 6               | max(DR-2,0)
 * 7               | max(DR-3,0)
 * 8               | max(DR-3,0)
 *
 * Note, that if NbTrials is set to 1 or 2, the MAC will not decrease
 * the datarate, in case the LoRaMAC layer did not receive an acknowledgment
 */
uint8_t confirmedNbTrials = 4;

// Functions
void readBatteryVoltage()
{
	BatteryVoltage = getBatteryVoltage();
	DEBUG_PRINTLN("");
	DEBUG_PRINT("BatteryVoltage: ");
	DEBUG_PRINTLN(BatteryVoltage);
}

void readSensorBME280(void)
{
	
	// Start bme280
	if (!bme280.init())
	{
		// debug
		DEBUG_PRINTLN("");
		DEBUG_PRINTLN("Failed to initialize bme280");
	} else{
		DEBUG_PRINTLN("");
		DEBUG_PRINTLN("bme280 begin");

		delay(1000); // Bad read without delay

		// Read sensor BME280
		float temp_bme280 = bme280.getTemperature(); 
		float humi_bme280 = bme280.getHumidity(); 
		float pres_bme280 = bme280.getPressure();
		float alti_bme280 = bme280.calcAltitude(pres_bme280);

		// get and print temperatures
		DEBUG_PRINT("Temp: ");
		int_temp_bme280 = temp_bme280 * 100;
		DEBUG_PRINT(temp_bme280);
		DEBUG_PRINT(" C => ");
		DEBUG_PRINT(int_temp_bme280);
		DEBUG_PRINTLN(" ttn");

		// get and print humidity data
		DEBUG_PRINT("Humidity: ");

		int_humi_bme280 = humi_bme280 * 100;
		DEBUG_PRINT(humi_bme280);
		DEBUG_PRINT(" % => ");
		DEBUG_PRINT(int_humi_bme280);
		DEBUG_PRINTLN(" ttn");

		// get and print atmospheric pressure data
		DEBUG_PRINT("Pressure: ");
		int_pres_bme280 = pres_bme280 / 10;
		DEBUG_PRINT(pres_bme280);
		DEBUG_PRINT(" Pa => ");
		DEBUG_PRINT(int_pres_bme280);
		DEBUG_PRINTLN(" ttn");

		// get and print altitude data
		DEBUG_PRINT("Altitude: ");
		int_alti_bme280 = alti_bme280 * 10;
		DEBUG_PRINT(alti_bme280);
		DEBUG_PRINT(" m => ");
		DEBUG_PRINT(int_alti_bme280);
		DEBUG_PRINTLN(" ttn");
	}
}

void readSensorBH1750(void)
{

	// Sensor BH1750
	if (!lightMeter.begin()) {
		DEBUG_PRINTLN("");
    	DEBUG_PRINTLN("Failed to initialize lightMeter");
  	} else {
		DEBUG_PRINTLN("");
		DEBUG_PRINTLN(F("lightMeter begin"));

		delay(100); // Bad read without delay

		float lux_bh1750 = lightMeter.readLightLevel(); 

		// get and print lux
		DEBUG_PRINT("Light: ");
		int_lux_bh1750 = lux_bh1750;
		DEBUG_PRINT(lux_bh1750);
		DEBUG_PRINT(" lx => ");
		DEBUG_PRINT(int_lux_bh1750);
		DEBUG_PRINTLN(" ttn");
	}

}

void readSensorAds1115(void)
{
  //DEBUG_PRINTLN("Getting single-ended readings from AIN0..3");
  //DEBUG_PRINTLN("ADC Range: +/- 6.144V (1 bit = 3mV/ADS1015, 0.1875mV/ADS1115)");

  // The ADC input range (or gain) can be changed via the following
  // functions, but be careful never to exceed VDD +0.3V max, or to
  // exceed the upper and lower limits if you adjust the input range!
  // Setting these values incorrectly may destroy your ADC!
  //                                                                ADS1015  ADS1115
  //                                                                -------  -------
  // ads.setGain(GAIN_TWOTHIRDS);  // 2/3x gain +/- 6.144V  1 bit = 3mV      0.1875mV (default)
  // ads.setGain(GAIN_ONE);        // 1x gain   +/- 4.096V  1 bit = 2mV      0.125mV
  // ads.setGain(GAIN_TWO);        // 2x gain   +/- 2.048V  1 bit = 1mV      0.0625mV
  // ads.setGain(GAIN_FOUR);       // 4x gain   +/- 1.024V  1 bit = 0.5mV    0.03125mV
  // ads.setGain(GAIN_EIGHT);      // 8x gain   +/- 0.512V  1 bit = 0.25mV   0.015625mV
  // ads.setGain(GAIN_SIXTEEN);    // 16x gain  +/- 0.256V  1 bit = 0.125mV  0.0078125mV
  

	if (!ads1115_found) {
		DEBUG_PRINTLN("");
    	DEBUG_PRINTLN("Failed to initialize ADS1115");
  	} else {
		DEBUG_PRINTLN("");
		DEBUG_PRINTLN(F("ADS1115 begin"));
	
		/* Be sure to update this value based on the IC and the gain settings! */
		// float   multiplier = 3.0F;    /* ADS1015 @ +/- 6.144V gain (12-bit results) */
		//float multiplier = 0.1875F; /* ADS1115  @ +/- 6.144V gain (16-bit results) */
		float volts0, volts1, volts2, volts3;

		int_adc0 = ads.readADC_SingleEnded(0);
		//int_adc1 = ads.readADC_SingleEnded(1);
		int_adc1 = 0;
		//int_adc2 = ads.readADC_SingleEnded(2);
		int_adc2 = 0;	
		//int_adc3 = ads.readADC_SingleEnded(3);
		int_adc3 = 0;

		// Percent Humidity only one 
		int_perHum0 = map(int_adc0, 15400,7100,0,100);
		int_perHum1 = 0;
		int_perHum2 = 0;
		int_perHum3 = 0;
		
		DEBUG_PRINT("AIN0: ");
		volts0 = ads.computeVolts(int_adc0);
		DEBUG_PRINT(volts0);
		DEBUG_PRINT(" => ");
		DEBUG_PRINT(int_adc0);
		DEBUG_PRINT(" ttn ");
		DEBUG_PRINT(" PerHum0: ");
		DEBUG_PRINT(int_perHum0);
		DEBUG_PRINTLN(" ttn");

		DEBUG_PRINT("AIN1: ");
		volts1 = ads.computeVolts(int_adc1);
		DEBUG_PRINT(volts1);
		DEBUG_PRINT(" => ");
		DEBUG_PRINT(int_adc1);
		DEBUG_PRINT(" ttn ");
		DEBUG_PRINT(" PerHum1: ");
		DEBUG_PRINT(int_perHum1);
		DEBUG_PRINTLN(" ttn");

		DEBUG_PRINT("AIN2: ");
		volts2 = ads.computeVolts(int_adc2);
		DEBUG_PRINT(volts2);
		DEBUG_PRINT(" => ");
		DEBUG_PRINT(int_adc2);
		DEBUG_PRINT(" ttn ");
		DEBUG_PRINT(" PerHum2: ");
		DEBUG_PRINT(int_perHum2);
		DEBUG_PRINTLN(" ttn");

		DEBUG_PRINT("AIN3: ");
		volts3 = ads.computeVolts(int_adc3);
		DEBUG_PRINT(volts3);
		DEBUG_PRINT(" => ");
		DEBUG_PRINT(int_adc3);
		DEBUG_PRINT(" ttn ");
		DEBUG_PRINT(" PerHum0: ");
		DEBUG_PRINT(int_perHum3);
		DEBUG_PRINTLN(" ttn");
		DEBUG_PRINTLN("");
	}

}

void readSensors(){
	// Vext ON
	pinMode(Vext, OUTPUT);
	digitalWrite(Vext, LOW);
	delay(100); // Bad read without delay

	// debug
	DEBUG_PRINTLN("");
	DEBUG_PRINTLN("Read sensors");

	readSensorBME280();
	
	readSensorBH1750();
	
	readSensorAds1115();
	
	// Necesario para que vuelva a funcionar despues del Sleep
	Wire.end();
	delay(100);		

	// Vext OFF
	digitalWrite(Vext, HIGH);
	delay(50);		
}

/* Prepares the payload of the frame */
static void prepareTxFrame(uint8_t port)
{
	/*appData size is LORAWAN_APP_DATA_MAX_SIZE which is defined in "commissioning.h".
	 *appDataSize max value is LORAWAN_APP_DATA_MAX_SIZE.
	 *if enabled AT, don't modify LORAWAN_APP_DATA_MAX_SIZE, it may cause system hanging or failure.
	 *if disabled AT, LORAWAN_APP_DATA_MAX_SIZE can be modified, the max value is reference to lorawan region and SF.
	 *for example, if use REGION_CN470,
	 *the max value for different DR can be found in MaxPayloadOfDatarateCN470 refer to DataratesCN470 and BandwidthsCN470 in "RegionCN470.h".
	 */
	readBatteryVoltage();
	readSensors();

	appDataSize = 24;
	// Battery
	appData[0] = (uint8_t)(BatteryVoltage >> 8);
	appData[1] = (uint8_t)BatteryVoltage;
	// Temperature bme280
	appData[2] = (uint8_t)(int_temp_bme280 >> 8);
	appData[3] = (uint8_t)int_temp_bme280;
	// Humidity bme280
	appData[4] = (uint8_t)(int_humi_bme280 >> 8);
	appData[5] = (uint8_t)int_humi_bme280;
	// Pressure bme280
	appData[6] = (uint8_t)(int_pres_bme280 >> 8);
	appData[7] = (uint8_t)int_pres_bme280;
	// Altitude bme280
	appData[8] = (uint8_t)(int_alti_bme280 >> 8);
	appData[9] = (uint8_t)int_alti_bme280;
	// Lux bh1750
	appData[10] = (uint8_t)(int_lux_bh1750 >> 8);
	appData[11] = (uint8_t)int_lux_bh1750;
	// Ads1115 
	appData[12] = (uint8_t)(int_adc0 >> 8);
	appData[13] = (uint8_t)int_adc0;
	appData[14] = (uint8_t)(int_adc1 >> 8);
	appData[15] = (uint8_t)int_adc1;
	appData[16] = (uint8_t)(int_adc2 >> 8);
	appData[17] = (uint8_t)int_adc2;
	appData[18] = (uint8_t)(int_adc3 >> 8);
	appData[19] = (uint8_t)int_adc3;
	// Ads1115 percent humidity 
	appData[20] = (uint8_t)int_perHum0;
	appData[21] = (uint8_t)int_perHum1;
	appData[22] = (uint8_t)int_perHum2;
	appData[23] = (uint8_t)int_perHum3;
	
}

// downlink data handle function example
/*
void downLinkDataHandle(McpsIndication_t *mcpsIndication)
{
	DEBUG_PRINTF("+REV DATA:%s,RXSIZE %d,PORT %d\r\n", mcpsIndication->RxSlot ? "RXWIN2" : "RXWIN1", mcpsIndication->BufferSize, mcpsIndication->Port);
	DEBUG_PRINT("+REV DATA:");
	for (uint8_t i = 0; i < mcpsIndication->BufferSize; i++)
	{
		DEBUG_PRINTF("%02X", mcpsIndication->Buffer[i]);
	}
	DEBUG_PRINTLN();
	uint32_t color = mcpsIndication->Buffer[0] << 16 | mcpsIndication->Buffer[1] << 8 | mcpsIndication->Buffer[2];
#if (LoraWan_RGB == 1)
	turnOnRGB(color, 5000);
	turnOffRGB();
#endif
}
*/

void setup()
{
#ifdef DEBUG	
	Serial.begin(115200);
#endif	

#if (AT_SUPPORT)
	enableAt();
#endif

	// Vext ON
	pinMode(Vext, OUTPUT);
	digitalWrite(Vext, LOW);
	delay(100);
	// debug
	DEBUG_PRINTLN("");
	DEBUG_PRINTLN("Setup sensors");

	if (!ads.begin()) {
		DEBUG_PRINTLN("");
    	DEBUG_PRINTLN("Failed to initialize ADS1115");
  	} else {
		DEBUG_PRINTLN("");
		DEBUG_PRINTLN(F("ADS1115 begin"));
		ads1115_found = true;
	}
	
	// Necesario para liberar el I2C 
	Wire.end();
	delay(100);		

	// Vext OFF
	digitalWrite(Vext, HIGH);
	delay(50);		

	deviceState = DEVICE_STATE_INIT;
	LoRaWAN.ifskipjoin();

}

void loop()
{
	switch (deviceState)
	{
	case DEVICE_STATE_INIT:
	{
#if (LORAWAN_DEVEUI_AUTO)
		LoRaWAN.generateDeveuiByChipID();
#endif
#if (AT_SUPPORT)
		getDevParam();
#endif
		printDevParam();
		LoRaWAN.init(loraWanClass, loraWanRegion);
		deviceState = DEVICE_STATE_JOIN;
		break;
	}
	case DEVICE_STATE_JOIN:
	{
		LoRaWAN.join();
		break;
	}
	case DEVICE_STATE_SEND:
	{
		prepareTxFrame(appPort);
		LoRaWAN.send();
		deviceState = DEVICE_STATE_CYCLE;
		break;
	}
	case DEVICE_STATE_CYCLE:
	{
		// Schedule next packet transmission
		txDutyCycleTime = appTxDutyCycle + randr(0, APP_TX_DUTYCYCLE_RND);
		LoRaWAN.cycle(txDutyCycleTime);
		deviceState = DEVICE_STATE_SLEEP;
		break;
	}
	case DEVICE_STATE_SLEEP:
	{
		LoRaWAN.sleep();
		break;
	}
	default:
	{
		deviceState = DEVICE_STATE_INIT;
		break;
	}
	}
}

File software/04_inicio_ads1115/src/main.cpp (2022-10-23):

#include <Arduino.h>

#include <Wire.h>
#include <Adafruit_ADS1X15.h>

Adafruit_ADS1115 ads;  /* Use this for the 16-bit version */
// Adafruit_ADS1015 ads;     /* Use this for the 12-bit version */

#include "CubeCell_NeoPixel.h"
CubeCell_NeoPixel pixels(1, RGB, NEO_GRB + NEO_KHZ800);
uint8_t i=0;


void setup(void) 
{
  Serial.begin(115200);
  Serial.println("Hello!");
  
  Serial.println("Getting single-ended readings from AIN0..3");
  Serial.println("ADC Range: +/- 6.144V (1 bit = 3mV/ADS1015, 0.1875mV/ADS1115)");

  pinMode(Vext, OUTPUT);
  digitalWrite(Vext, LOW); //set vext to high
  
  pixels.begin(); // INITIALIZE NeoPixel strip object (REQUIRED)
  pixels.clear(); // Set all pixel colors to 'off'
  
  delay(500);
  
  // The ADC input range (or gain) can be changed via the following
  // functions, but be careful never to exceed VDD +0.3V max, or to
  // exceed the upper and lower limits if you adjust the input range!
  // Setting these values incorrectly may destroy your ADC!
  //                                                                ADS1015  ADS1115
  //                                                                -------  -------
  // ads.setGain(GAIN_TWOTHIRDS);  // 2/3x gain +/- 6.144V  1 bit = 3mV      0.1875mV (default)
  // ads.setGain(GAIN_ONE);        // 1x gain   +/- 4.096V  1 bit = 2mV      0.125mV
  // ads.setGain(GAIN_TWO);        // 2x gain   +/- 2.048V  1 bit = 1mV      0.0625mV
  // ads.setGain(GAIN_FOUR);       // 4x gain   +/- 1.024V  1 bit = 0.5mV    0.03125mV
  // ads.setGain(GAIN_EIGHT);      // 8x gain   +/- 0.512V  1 bit = 0.25mV   0.015625mV
  // ads.setGain(GAIN_SIXTEEN);    // 16x gain  +/- 0.256V  1 bit = 0.125mV  0.0078125mV
  
  ads.begin();
}

void loop(void) 
{
  int16_t adc0, adc1, adc2, adc3;
  
  // Calibrating soil moisture sensor
  // Adc values range 16 bits 0-65535 unsigned o −32768-32767 signed.
  // Adc value dry = 15400
  // Adc value wet = 7100

  int8_t percentHum0, percentHum1, percentHum2, percentHum3;

  float volts0, volts1, volts2, volts3;

  /* Be sure to update this value based on the IC and the gain settings! */
  //float   multiplier = 3.0F;    /* ADS1015 @ +/- 6.144V gain (12-bit results) */
  //float multiplier = 0.1875F; /* ADS1115  @ +/- 6.144V gain (16-bit results) */

  adc0 = ads.readADC_SingleEnded(0);
  adc1 = ads.readADC_SingleEnded(1);
  adc2 = ads.readADC_SingleEnded(2);
  adc3 = ads.readADC_SingleEnded(3);

  volts0 = ads.computeVolts(adc0);
  volts1 = ads.computeVolts(adc1);
  volts2 = ads.computeVolts(adc2);
  volts3 = ads.computeVolts(adc3);
  
  // Calibrating soil moisture sensor
  // Adc values range 16 bits 0-65535 unsigned o −32768-32767 signed.
  // Adc value dry = 15400
  // Adc value wet = 7100
  // Map
  //sensorValue = map(sensorvalue,valuedry,valuewet,0,100)
  percentHum0 = map(adc0, 15400,7100,0,100);

  Serial.print("AIN0: "); Serial.println(adc0);
  Serial.print("Vols0: "); Serial.println(volts0);
  Serial.print("Percent Humidity: "); Serial.print(percentHum0); Serial.println(" %");
  Serial.println(" ");
  
  Serial.print("AIN1: "); Serial.println(adc1);
  Serial.print("Volts1: "); Serial.println(volts1);
  Serial.println(" ");
  
  Serial.print("AIN2: "); Serial.println(adc2);
  Serial.print("Volts2: "); Serial.println(volts2);
  Serial.println(" ");

  Serial.print("AIN3: "); Serial.println(adc3);
  Serial.print("Volts3: "); Serial.println(volts3);
  Serial.println(" ");
  
  pixels.setPixelColor(0, pixels.Color(i, 0, i));
  pixels.show();   // Send the updated pixel colors to the hardware.

  delay(1000);

  i+=10;
  if (i>100) i =0;

}

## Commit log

2022-09-28 primer commit
    [AdaptadorCubeCellV1-B_Cu.gbl, AdaptadorCubeCellV1-B_Mask.gbs, AdaptadorCubeCellV1-B_Paste.gbp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]
2022-10-02 añado la lectura sensor BME280
2022-10-06 añado sensor BH1750 commit
2022-10-14 cambio de imagenes commit
2022-10-20 mejoras en la documentacion commit
2022-10-23 mejoras en sensor de humedad commit
2022-10-23 mejoras en sensor de humedad lorawan commit
2023-02-01 Corrección de porcentajes humedad
2023-03-01 solución a error al iniciar
    [main.cpp]
